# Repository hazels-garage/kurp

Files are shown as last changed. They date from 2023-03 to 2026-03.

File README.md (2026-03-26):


<a href="https://discord.gg/jP6hvgNN8r">
  
</a>

# Kurp
## 36 Key unibody split ortholinear

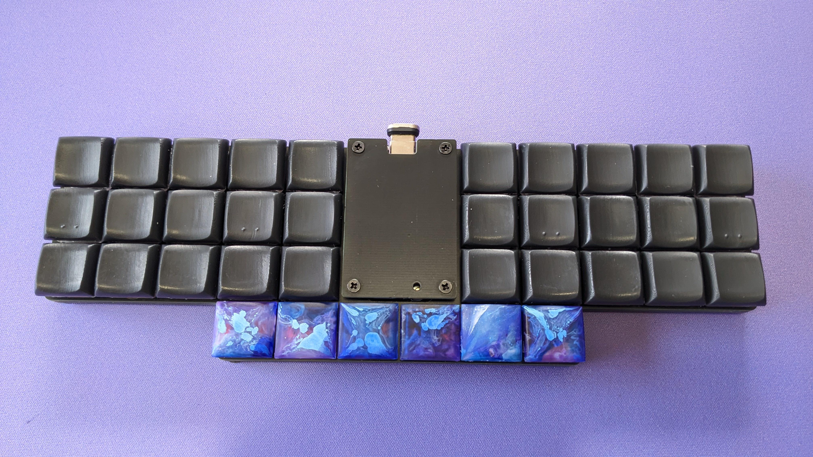
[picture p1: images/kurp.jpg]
build


## PCB Render
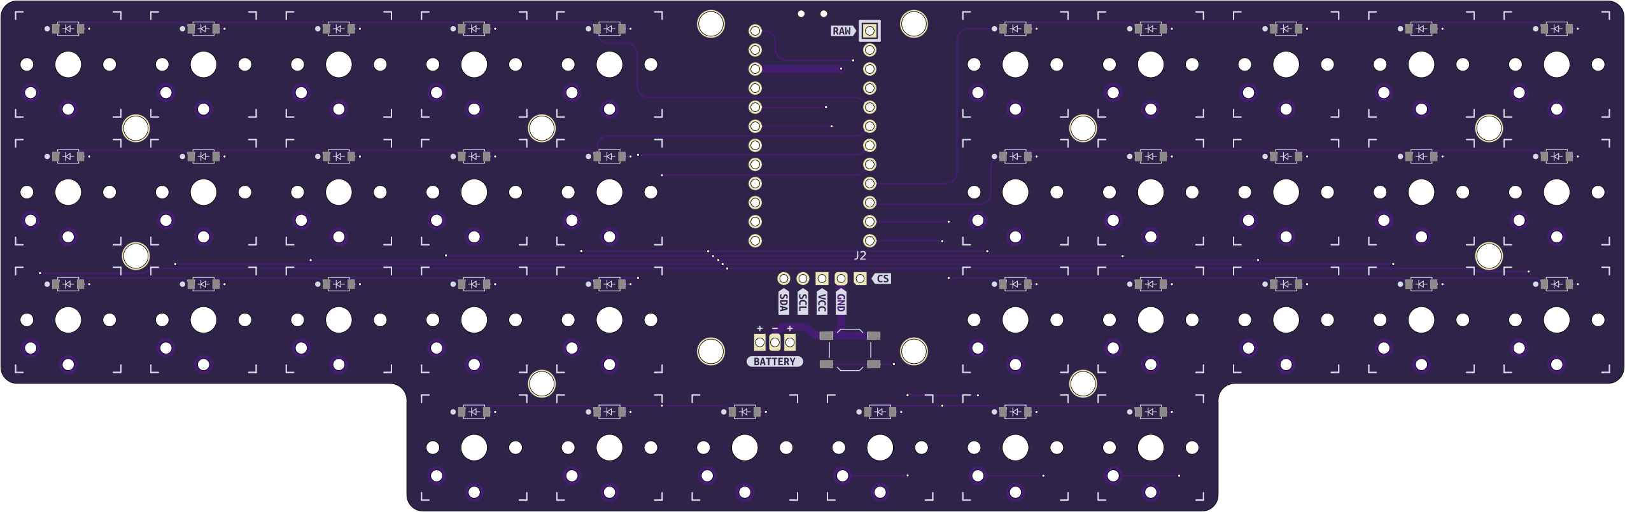
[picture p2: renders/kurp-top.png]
top

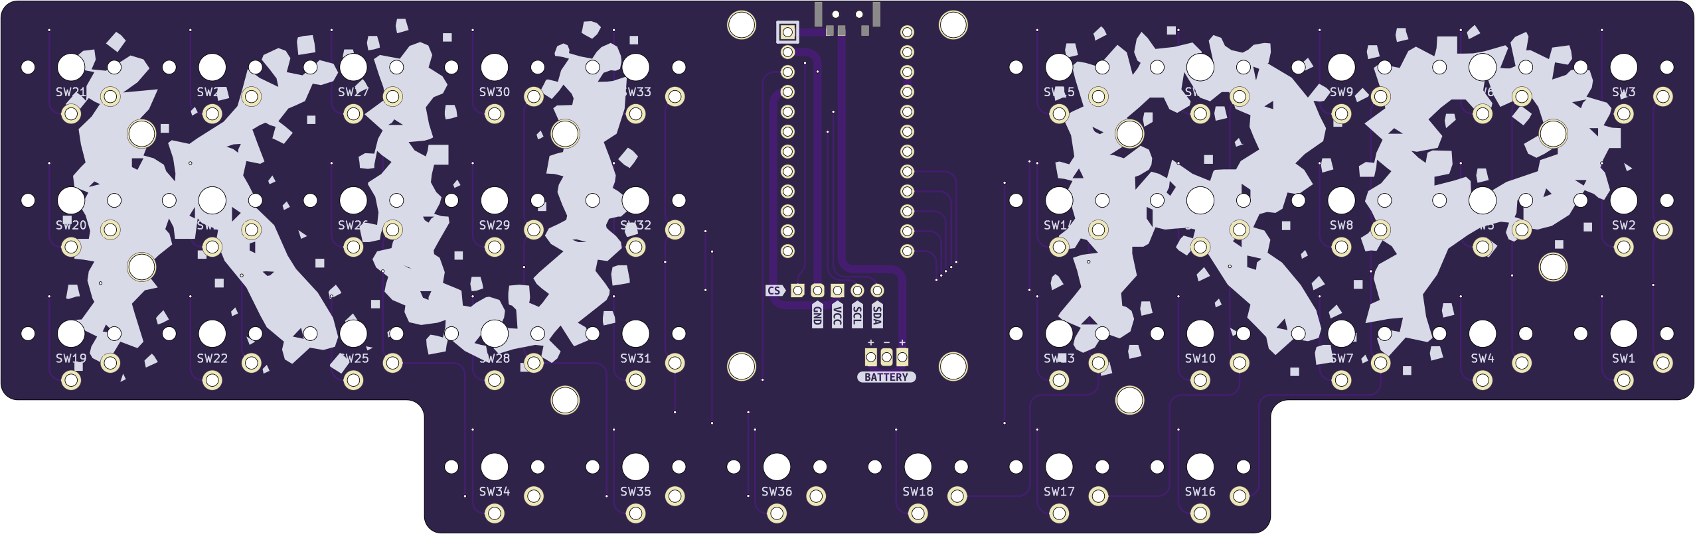
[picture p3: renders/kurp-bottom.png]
bottom


Kurp is a choc-spaced unibody split ortholinear keyboard.

## Materials

| Description | Part | Count | Notes |
| :---: | :---: | :---: | :---: |
| PCBs | [Main](pcbs/pcb/jlcpcb/production_files) | 1 | |
|| [Switchplate](pcbs/switchplate/jlcpcb/production_files) | 1 | Optional |
|| [Backplate](pcbs/backplate/jlcpcb/production_files) | 1 | Optional |
|| [Centerplate](pcbs/centerplate/jlcpcb/production_files) | 1 | Optional |
| Controller | ProMicro footprint | 1 |  | 
| Diodes | 1N4148 SOD-123  | 36 |  |
| Switches | Choc v1 | 36 |  | 
| Keycaps | 1u | 36 | |
| Reset | TL3342F260QG | 1 | |
| Display | SSD1306 | 1 | Optional |
| | nice!view |  | Wireless Only |
| Power Switch |  MSK-12C02 | 1 | Wireless Only | 
| Battery Connector | TBD | 1 | Optional, Wireless Only | 
| Battery | TBD | 1 | Wireless Only |
| 3mm M2 Standoff ||8||
| 9mm M2 Standoff ||4||
| 3mm M2 Screw ||24||

## Firmware
QMK : https://github.com/hazels-garage/qmk_firmware/tree/hazel/kurp

ZMK: https://github.com/hazels-garage/zmk-kurp

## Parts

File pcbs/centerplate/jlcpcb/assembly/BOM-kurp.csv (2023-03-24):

Comment | Designator | Footprint | LCSC
 | H4 | MountingHole_2.2mm_M2
 | H3 | MountingHole_2.2mm_M2
 | H2 | MountingHole_2.2mm_M2
 | H1 | MountingHole_2.2mm_M2
 | RESET1 | MountingHole_2.2mm_M2

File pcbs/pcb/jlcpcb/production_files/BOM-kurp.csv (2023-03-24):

Comment | Designator | Footprint | LCSC
SW_SPDT | PWR1 | SPDT_C128955 | C128955
SW | RESET1 | SW_SPST_TL3342 | C2886894
D | D1,D10,D11,D12,D13,D14,D15,D16,D17,D18,D19,D2,D20,D21,D22,D23,D24,D25,D26,D27,D28,D29,D3,D30,D31,D32,D33,D34,D35,D36,D4,D5,D6,D7,D8,D9 | D_SOD-123_via | C81598

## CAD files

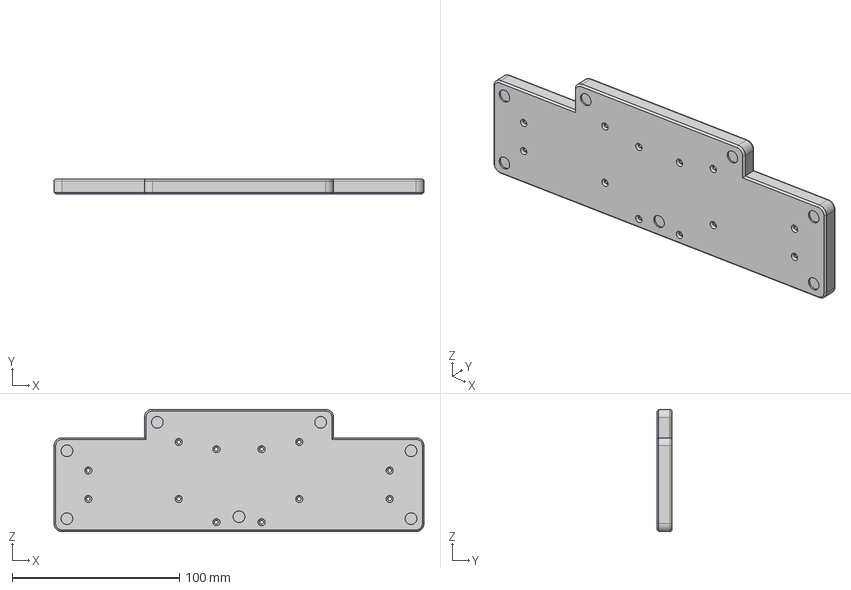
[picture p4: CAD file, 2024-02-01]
case/case-uniform-lip.step
221.0 x 9.00 x 73.0 mm

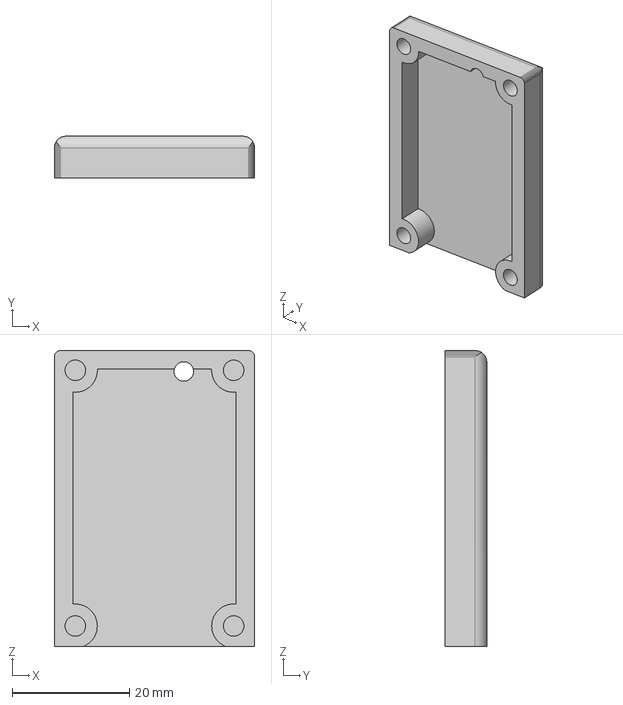
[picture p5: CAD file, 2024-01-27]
case/mcu-cover.step
34.1 x 7.10 x 50.5 mm

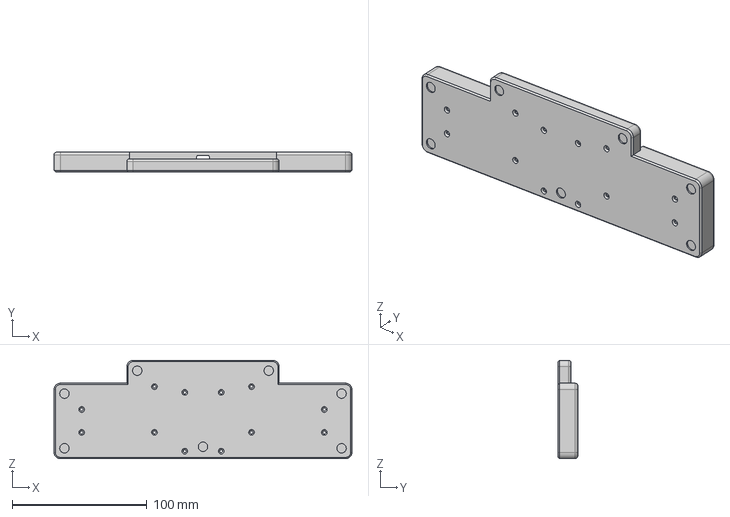
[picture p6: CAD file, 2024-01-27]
case/case.step
221.0 x 14.6 x 73.0 mm

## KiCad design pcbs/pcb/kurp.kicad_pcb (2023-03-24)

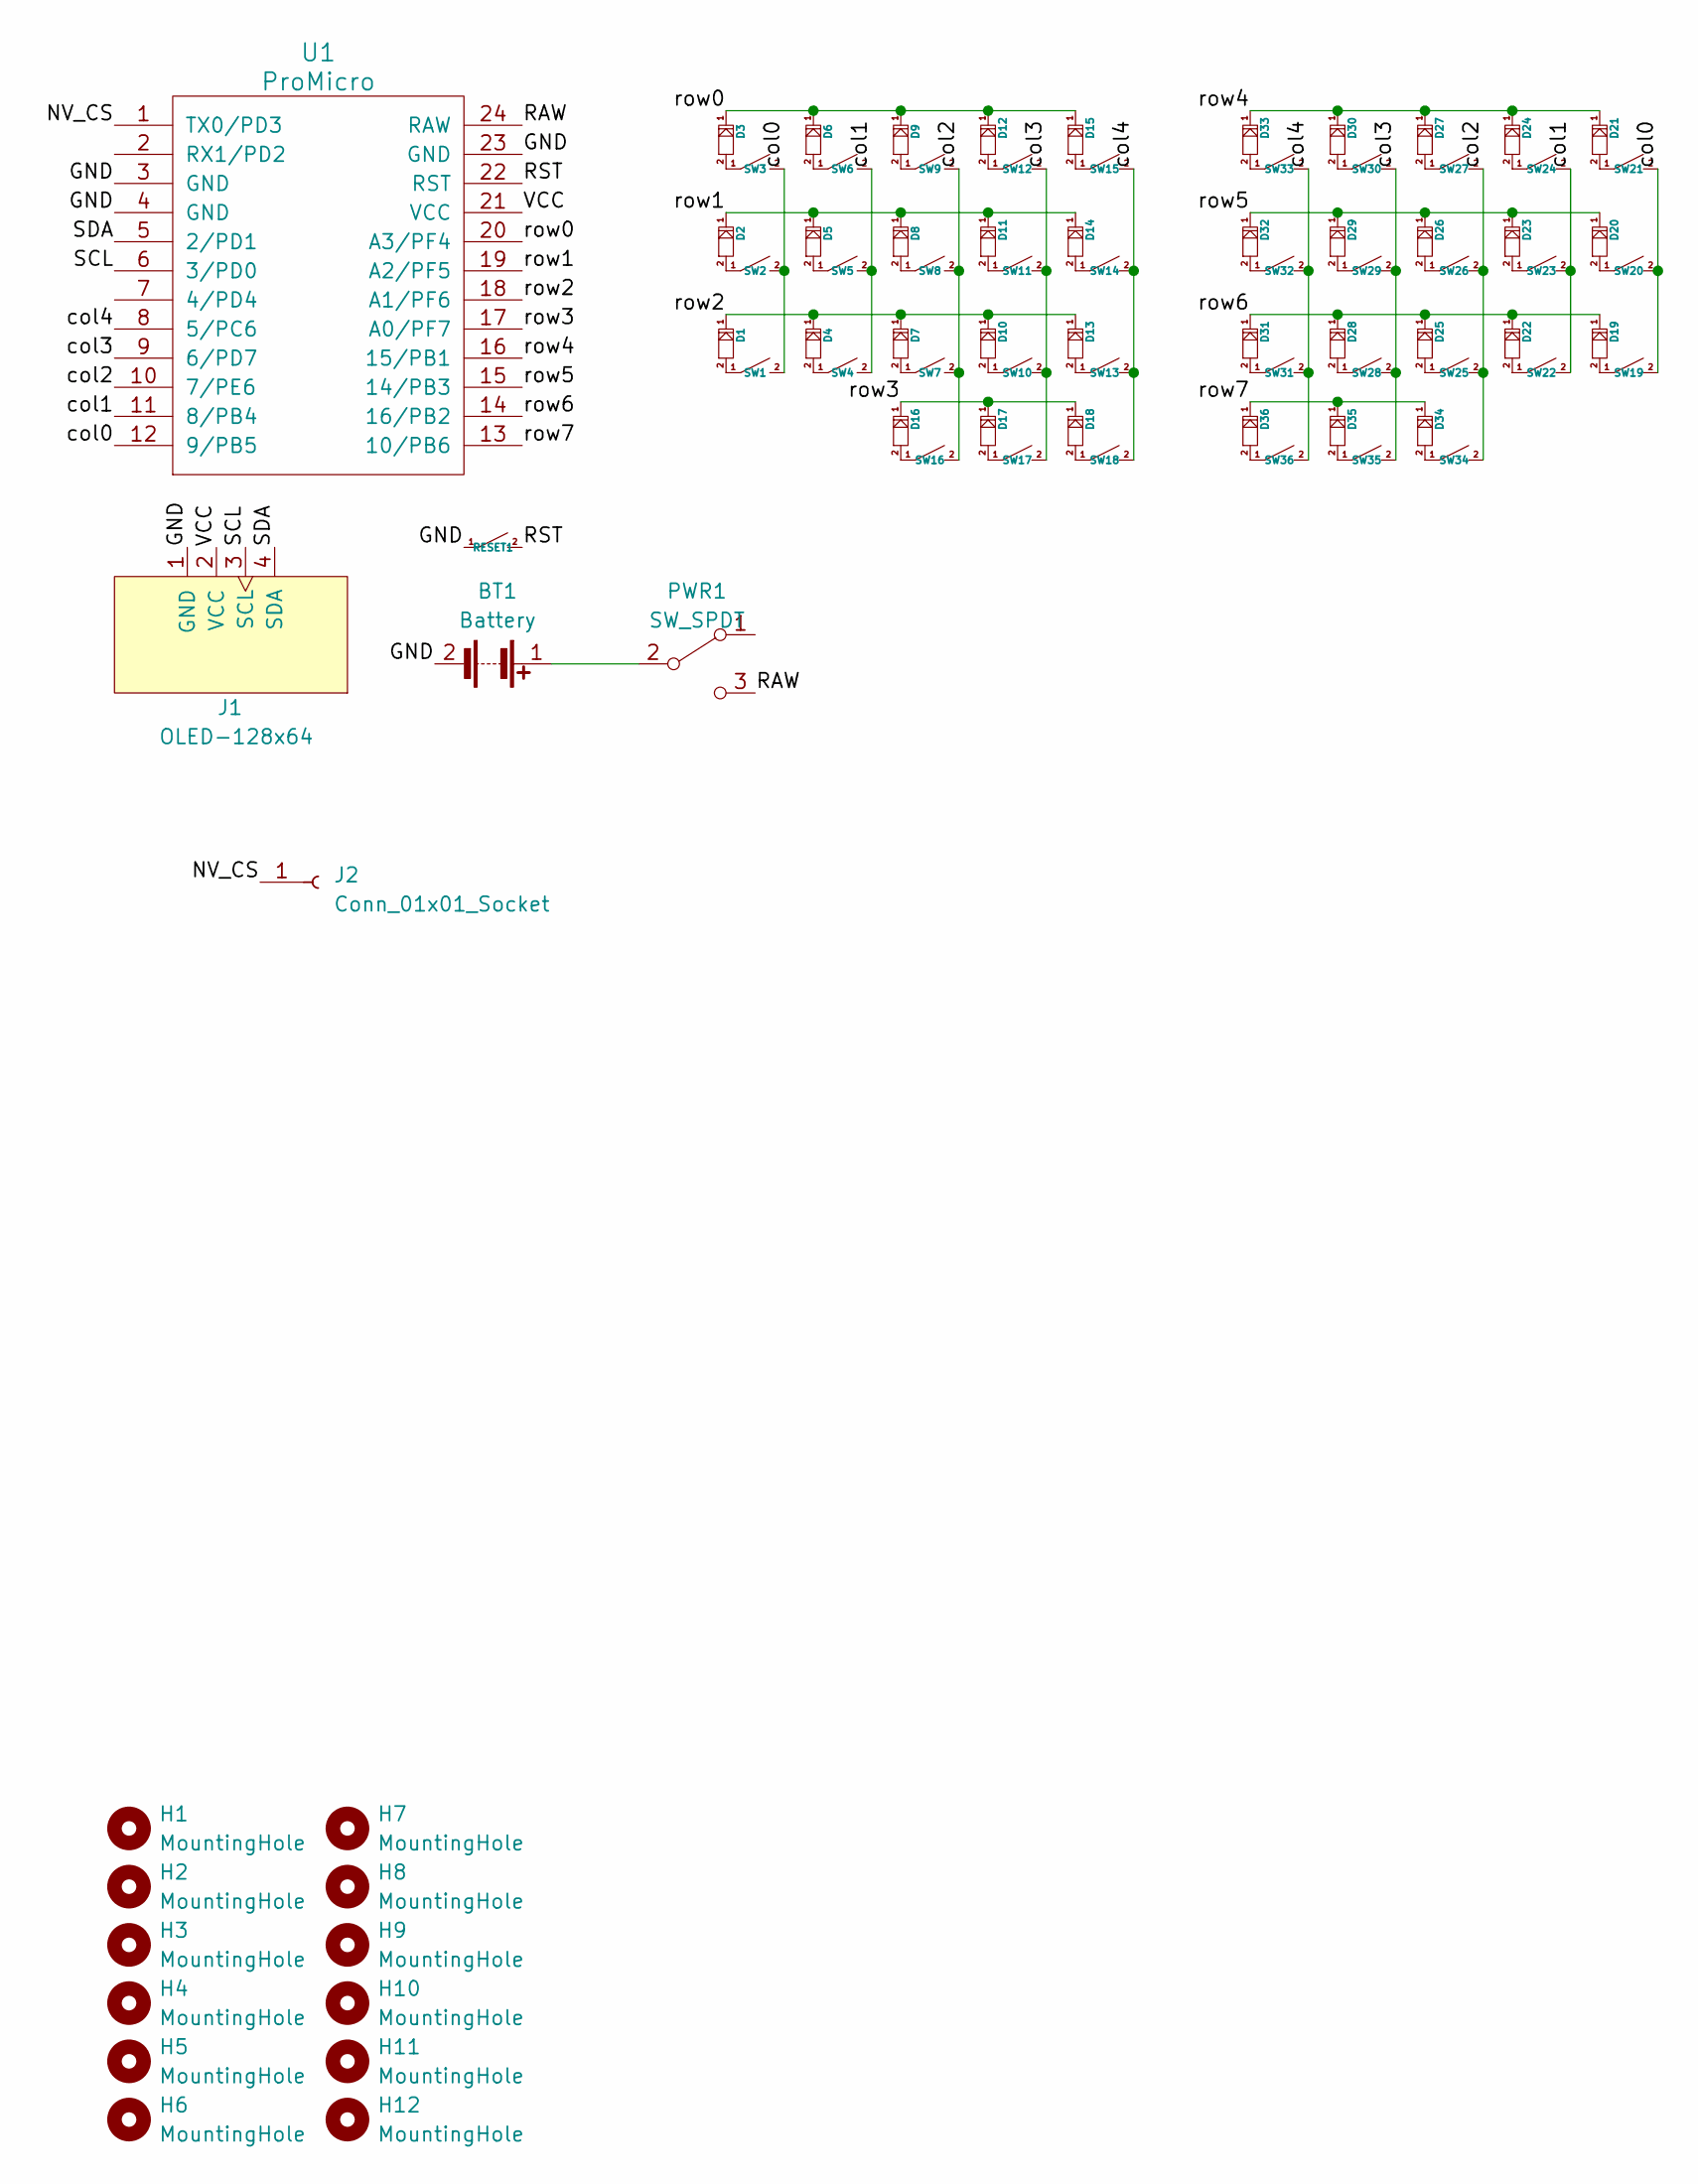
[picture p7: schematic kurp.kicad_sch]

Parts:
BT1: Battery; 3JST_BAT
D1, D2, D3, D4, D5, D6, D7, D8, D9, D10, D11, D12, D13, D14, D15, D16, D17, D18, D19, D20, D21, D22, D23, D24, D25, D26, D27, D28, D29, D30, D31, D32, D33, D34, D35, D36: D; D_SOD-123_via
H1, H2, H3, H4, H5, H6, H7, H8, H9, H10, H11, H12: MountingHole; MountingHole_3.2mm_M3_thinpad
J1: OLED-128x64
J2: Conn_01x01_Socket; CS_PIN
PWR1: SW_SPDT; SPDT_C128955
RESET1: SW; SW_SPST_TL3342
SW1, SW2, SW3, SW4, SW5, SW6, SW7, SW8, SW9, SW10, SW11, SW12, SW13, SW14, SW15, SW16, SW17, SW18, SW19, SW20, SW21, SW22, SW23, SW24, SW25, SW26, SW27, SW28, SW29, SW30, SW31, SW32, SW33, SW34, SW35, SW36: SW; jh-choc
U1: ProMicro; ArduinoProMicro

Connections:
/GND: BT1.2 (-), J1.1 (GND), RESET1.1, U1.3 (GND), U1.4 (GND), U1.23 (GND)
/NV_CS: J2.1, U1.1 (TX0/PD3)
/RAW: PWR1.3 (C), U1.24 (RAW)
/RST: RESET1.2, U1.22 (RST)
/SCL: J1.3 (SCL), U1.6 (3/PD0)
/SDA: J1.4 (SDA), U1.5 (2/PD1)
/VCC: J1.2 (VCC), U1.21 (VCC)
/col0: SW1.2, SW2.2, SW3.2, SW19.2, SW20.2, SW21.2, U1.12 (9/PB5)
/col1: SW4.2, SW5.2, SW6.2, SW22.2, SW23.2, SW24.2, U1.11 (8/PB4)
/col2: SW7.2, SW8.2, SW9.2, SW16.2, SW25.2, SW26.2, SW27.2, SW34.2, U1.10 (7/PE6)
/col3: SW10.2, SW11.2, SW12.2, SW17.2, SW28.2, SW29.2, SW30.2, SW35.2, U1.9 (6/PD7)
/col4: SW13.2, SW14.2, SW15.2, SW18.2, SW31.2, SW32.2, SW33.2, SW36.2, U1.8 (5/PC6)
/row0: D3.1, D6.1, D9.1, D12.1, D15.1, U1.20 (A3/PF4)
/row1: D2.1, D5.1, D8.1, D11.1, D14.1, U1.19 (A2/PF5)
/row2: D1.1, D4.1, D7.1, D10.1, D13.1, U1.18 (A1/PF6)
/row3: D16.1, D17.1, D18.1, U1.17 (A0/PF7)
/row4: D21.1, D24.1, D27.1, D30.1, D33.1, U1.16 (15/PB1)
/row5: D20.1, D23.1, D26.1, D29.1, D32.1, U1.15 (14/PB3)
/row6: D19.1, D22.1, D25.1, D28.1, D31.1, U1.14 (16/PB2)
/row7: D34.1, D35.1, D36.1, U1.13 (10/PB6)
unnamed: BT1.1 (+), PWR1.2 (B)
unnamed: D1.2, SW1.1
unnamed: D2.2, SW2.1
unnamed: D3.2, SW3.1
unnamed: D4.2, SW4.1
unnamed: D5.2, SW5.1
unnamed: D6.2, SW6.1
unnamed: D7.2, SW7.1
unnamed: D8.2, SW8.1
unnamed: D9.2, SW9.1
unnamed: D10.2, SW10.1
unnamed: D11.2, SW11.1
unnamed: D12.2, SW12.1
unnamed: D13.2, SW13.1
unnamed: D14.2, SW14.1
unnamed: D15.2, SW15.1
unnamed: D16.2, SW16.1
unnamed: D17.2, SW17.1
unnamed: D18.2, SW18.1
unnamed: D19.2, SW19.1
unnamed: D20.2, SW20.1
unnamed: D21.2, SW21.1
unnamed: D22.2, SW22.1
unnamed: D23.2, SW23.1
unnamed: D24.2, SW24.1
unnamed: D25.2, SW25.1
unnamed: D26.2, SW26.1
unnamed: D27.2, SW27.1
unnamed: D28.2, SW28.1
unnamed: D29.2, SW29.1
unnamed: D30.2, SW30.1
unnamed: D31.2, SW31.1
unnamed: D32.2, SW32.1
unnamed: D33.2, SW33.1
unnamed: D34.2, SW34.1
unnamed: D35.2, SW35.1
unnamed: D36.2, SW36.1

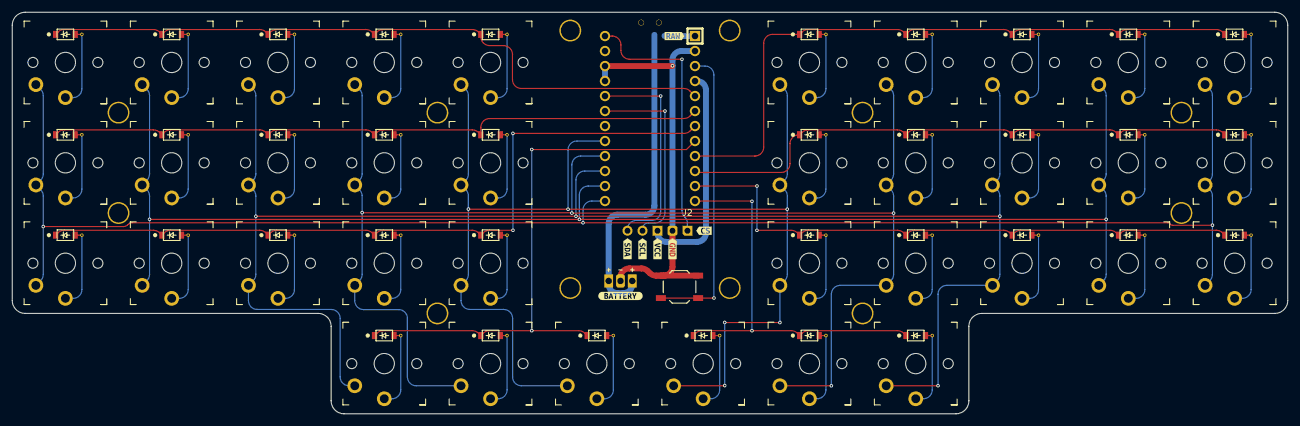
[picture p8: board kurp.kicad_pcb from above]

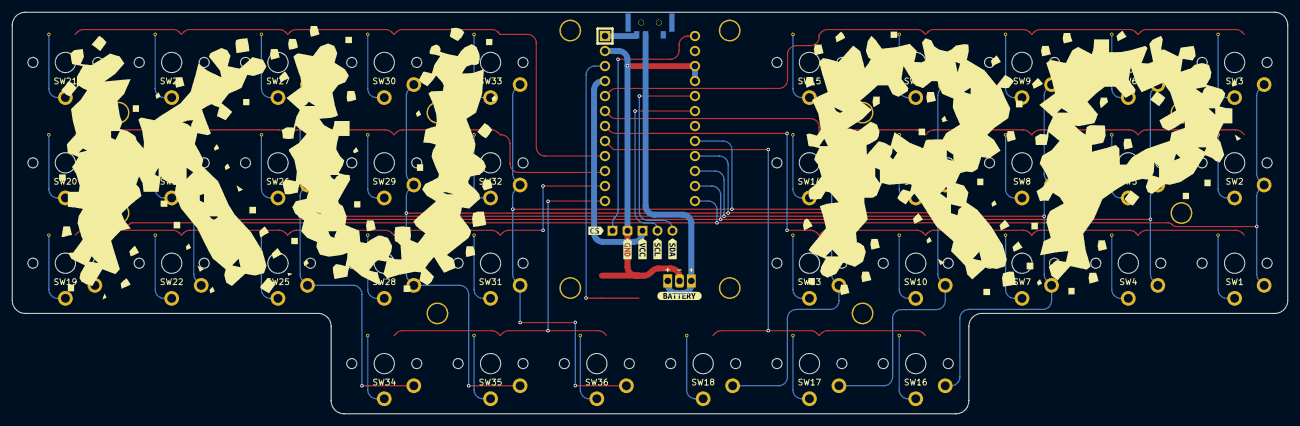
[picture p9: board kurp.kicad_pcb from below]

Board: 2 copper layers, 216.0 x 68.0 mm, 92 parts (3 on the bottom side), 57 nets.

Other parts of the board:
kibuzzard-641D257F: G***; kibuzzard-641D257F
kibuzzard-641D2588: G***; kibuzzard-641D2588

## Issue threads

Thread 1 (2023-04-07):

Backplate cutout missing for nice!view

jasonhazel, 2023-04-07:
Made the backplate before adding nice!view support and forgot to update the OLED cutout to account for the extra CS pin.

Closed 2023-09-02.

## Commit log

2023-03-24 bump kicad version for kicad7
2023-03-24 add links to pcb fab files
2023-04-11 widen cutout for oled/niceview
    [kurp-CuBottom.gbr, kurp-CuTop.gbr, kurp-EdgeCuts.gbr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]
2023-04-11 actually save pcb changes
    [kurp.kicad_pcb]
2024-01-27 adding case steps
    [case.step, mcu-cover.step]
2024-02-01 adding version of case with lower, uniform switch skirt
    [case-uniform-lip.step]

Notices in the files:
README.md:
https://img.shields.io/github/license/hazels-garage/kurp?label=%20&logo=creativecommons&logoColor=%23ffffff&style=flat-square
